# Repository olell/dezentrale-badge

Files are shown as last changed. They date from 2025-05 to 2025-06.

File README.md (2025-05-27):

# Dezentrale Blinky Logo

## Update Firmware

You can flash the latest Firmware directly using your web browser using [CH32WebFlash](https://olell.github.io/CH32WebFlashTool/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)

## Photos

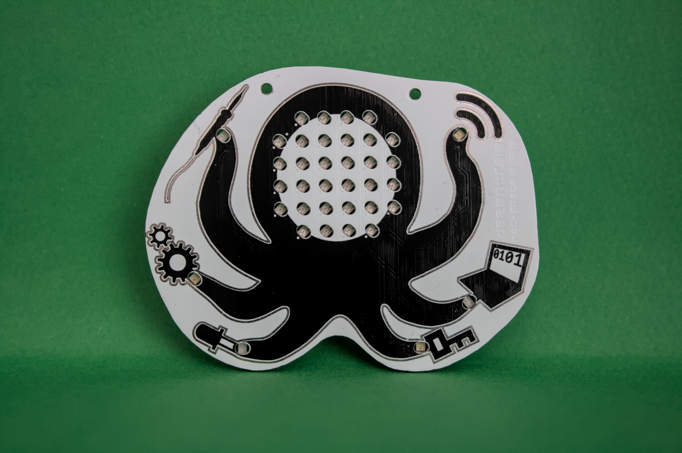
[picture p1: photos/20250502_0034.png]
front

back

## License

- Firmware source code is release under MIT License (C) 2025 Ole Lange
- The hardware is licensed under CC BY-NC-SA 4.0

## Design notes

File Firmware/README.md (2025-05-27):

# Dezentrale Badge Firmware

> **Note:** This project is a work in progress.

## Button actions:

| Press times | Action |
| --- | --- |
| 1x | Depends on animation |
| 2x | Depends on animation |
| 3x | Next animation |
| 4x | Go to sleep (wake by pressing the button) |
| 5x | Enter the USB bootloader |

## Setup

### 1. Toolchain

Find instructions to install the required dependencies and toolchain here: [ch32fun Installation Guide](https://github.com/cnlohr/ch32fun/wiki/Installation)

### 2. SDK

Run `git submodule update --init` to clone the ch32fun SDK

## Build & Flash

Navigate to the `Firmware` directory and run `make` to build and flash the firmware.

The provided `Makefile` includes a custom command for flashing the badge using an Ardulink programmer. If you need to change the serial port or use a different programmer, please update the Makefile accordingly. For the official WCH-LinkE, you can remove the custom flashing line.

### Flash using the USB bootloader

If your badge has the USB bootloader installed, you can flash it by connecting via USB. To enter the bootloader, follow these steps:

#### Option A: From firmware

You can enter the bootloader from firmware by pressing the button 5 times, the badge then starts to blink rapidly. To enter the
bootloader you now have to press the button again. By pressing the button 3x (animation change) you can abort entering the bootloader.

#### Option B: Pressing the button while power on

1. Remove the battery.
2. Insert the USB cable (if not already connected).
3. Press and hold the button.
4. Re-insert the battery while holding the button.

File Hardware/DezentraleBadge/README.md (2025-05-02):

# Dezentrale Badge Hardware Version 1

This folder contains the KiCad project for the BlinkyLogo V1

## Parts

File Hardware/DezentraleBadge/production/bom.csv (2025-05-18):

Designator | Footprint | Quantity | Value | LCSC Part #
BT101 | BatteryHolder_Multicomp_BC-2001_1x2032 | 1 | CR2032 | C6937139
C101 | 0805 | 1 | 100nF | C28233
D102, D103, D104, D105, D107, D108, D109, D110, D111, D112, D113, D114, D115, D116, D117, D118, D119, D120, D121, D122, D123, D124, D125, D126, D127, D128, D129, D130, D132, D133, D134, D135, D137, D138, D139, D140, D141, D142 | 1206 | 38 | LED_45deg | C3646940
J101 | Harwin_M20-89003xx_1x03_P2.54mm_Horizontal | 1 | PROG
J102 | USB_C_Receptacle_GCT_USB4110 | 1 | USB_C_Receptacle_USB2.0_16P
R101 | 0805 | 1 | 10kΩ | C17414
R102 | 0805 | 1 | 1.5kΩ | C17414
SW101 | SW_Push_1P1T_XKB_TS-1187A | 1 | Button | C318884
U101 | SOP-16_3.9x9.9mm_P1.27mm | 1 | CH32V003AxMx | C5346357

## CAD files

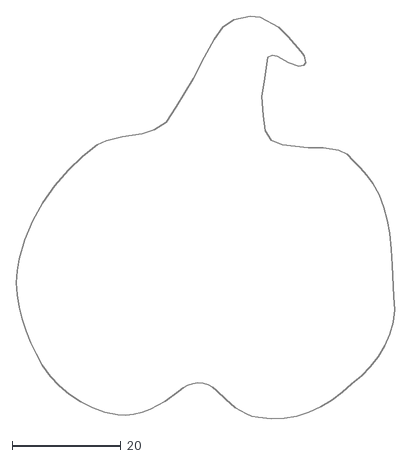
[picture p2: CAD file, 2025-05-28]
Hardware/Assets/outline_hacksen.dxf
69.7 x 74.2

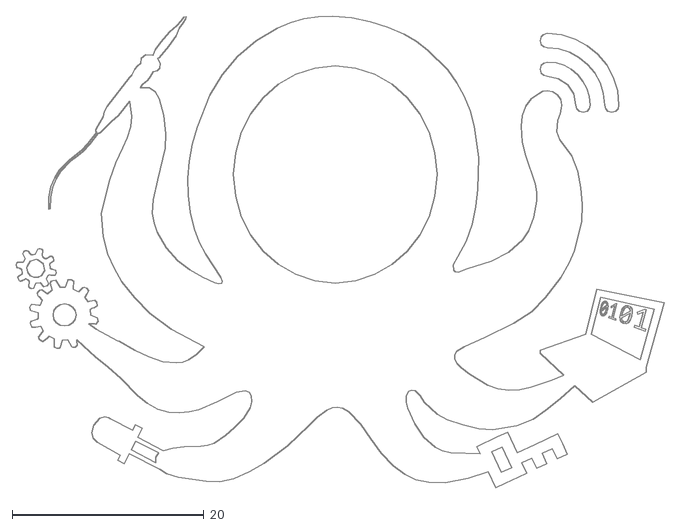
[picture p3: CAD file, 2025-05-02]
Hardware/Assets/dezentrale_logo_simple.dxf
67.6 x 49.1

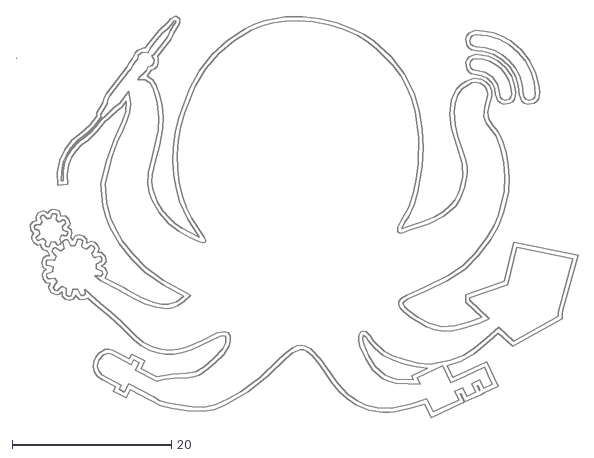
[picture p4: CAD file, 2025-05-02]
Hardware/Assets/extruded_outline.dxf
70.5 x 50.4

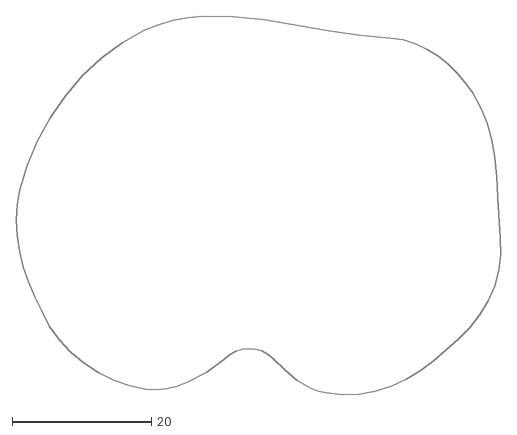
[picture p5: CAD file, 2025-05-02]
Hardware/Assets/outline.dxf
69.7 x 54.4

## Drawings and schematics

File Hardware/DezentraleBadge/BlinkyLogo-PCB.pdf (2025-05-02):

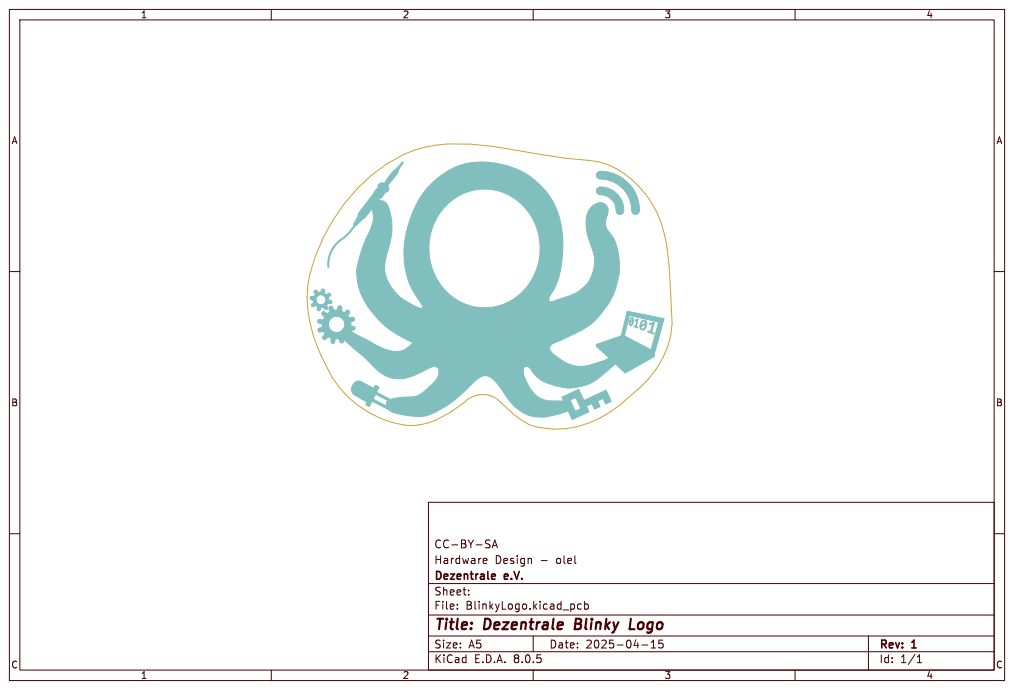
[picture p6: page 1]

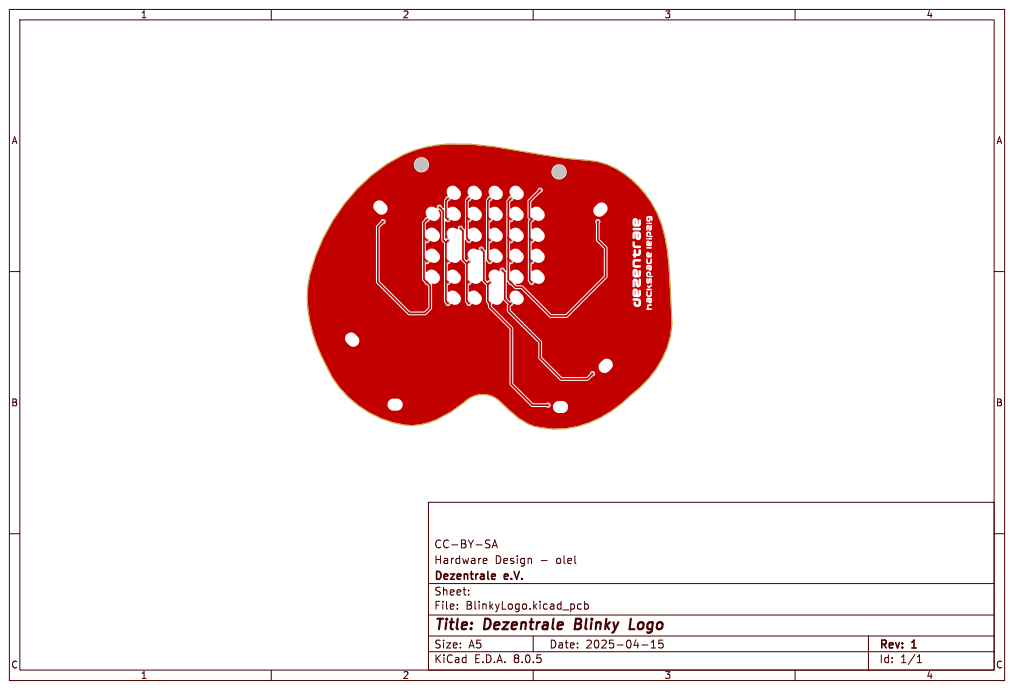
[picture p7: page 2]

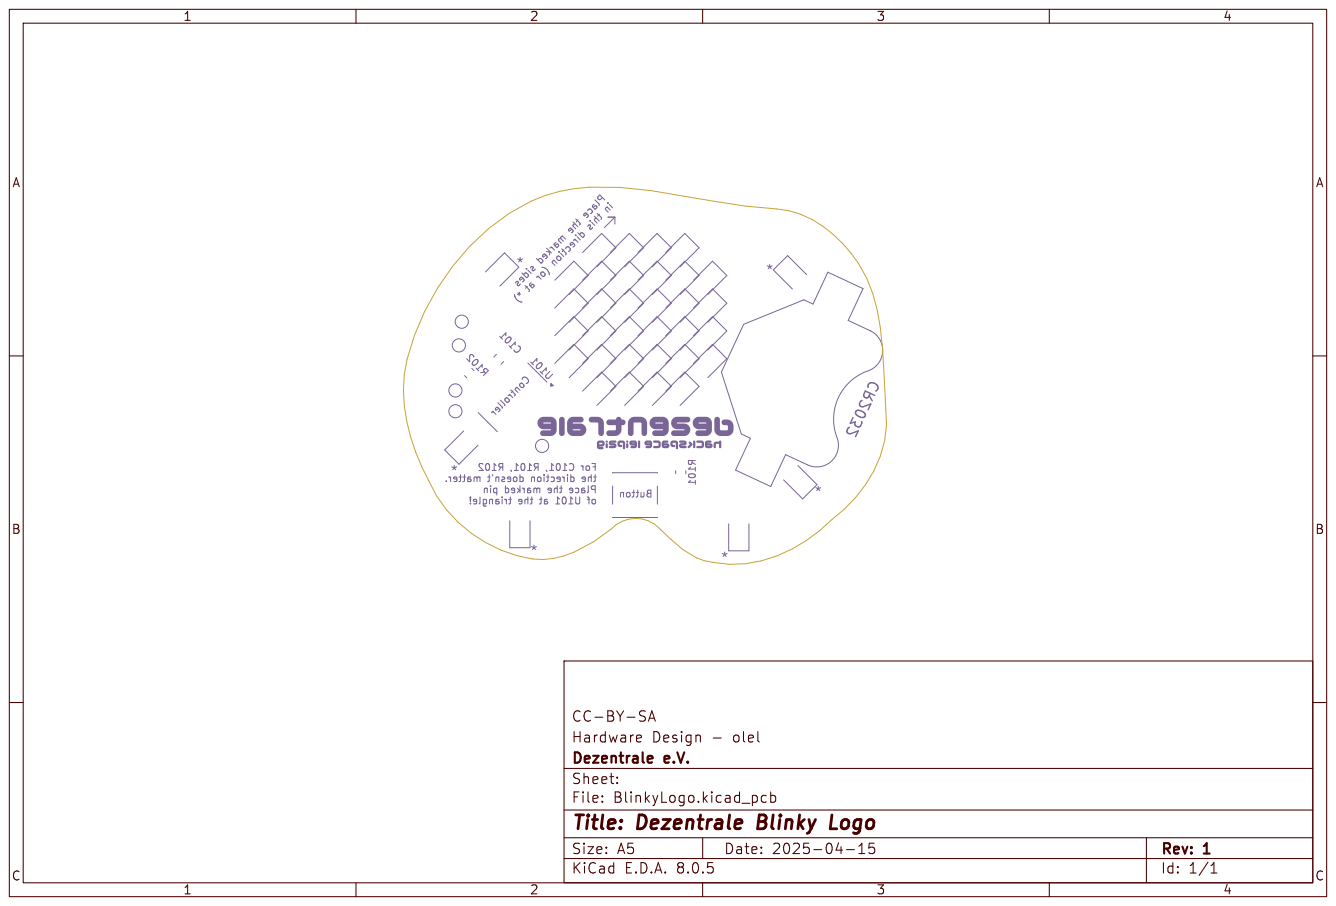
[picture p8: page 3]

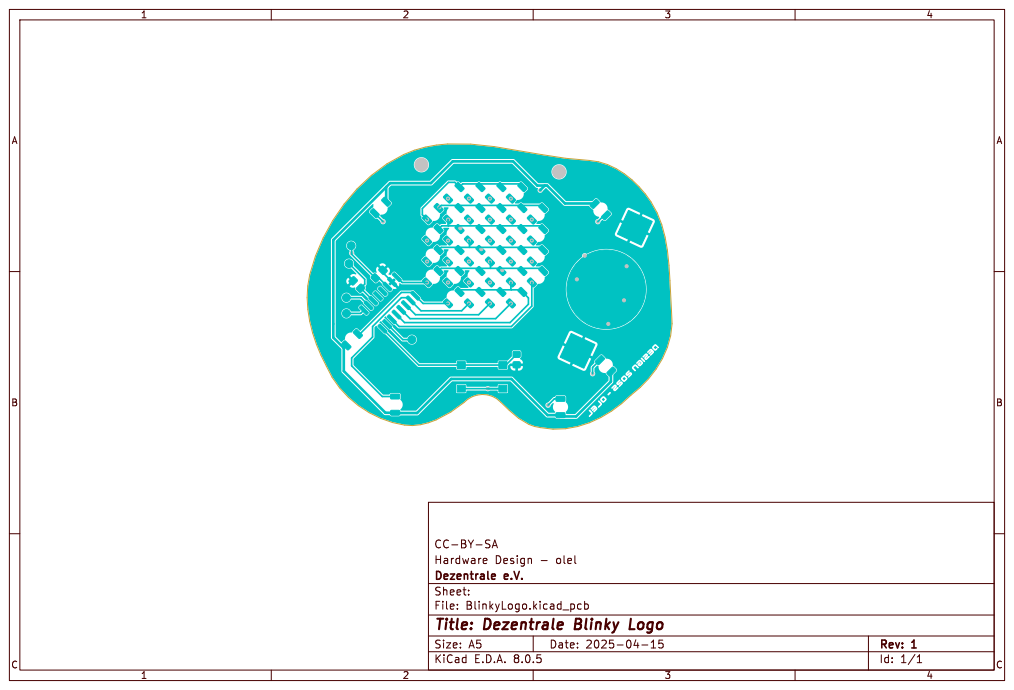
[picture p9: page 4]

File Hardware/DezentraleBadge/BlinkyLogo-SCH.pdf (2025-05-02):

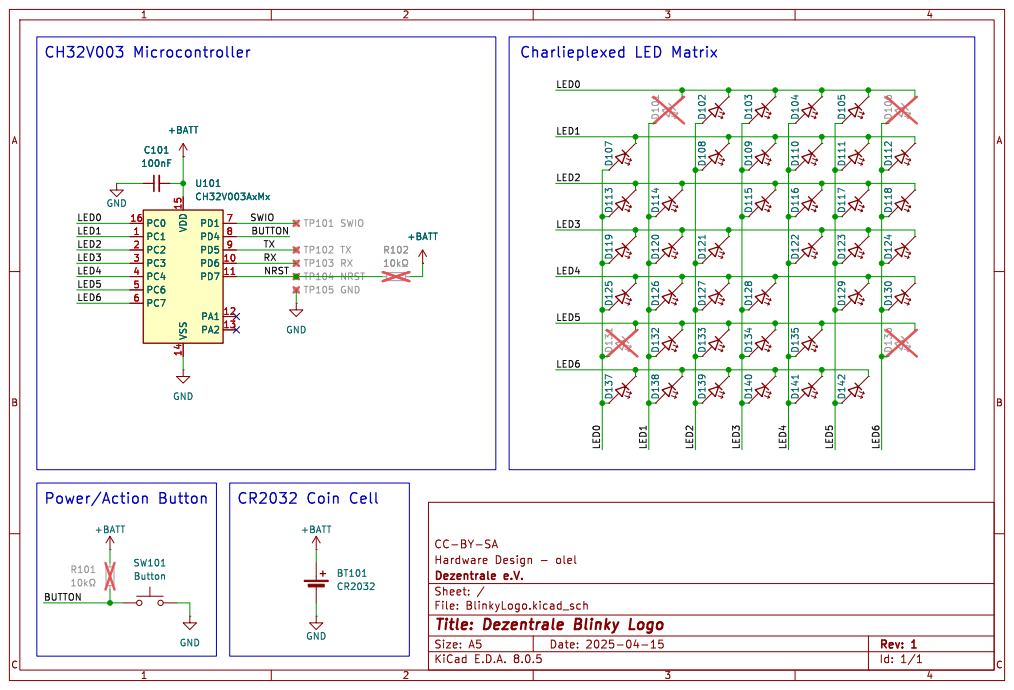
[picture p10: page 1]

Id: 1/1 Title: Dezentrale Blinky Logo

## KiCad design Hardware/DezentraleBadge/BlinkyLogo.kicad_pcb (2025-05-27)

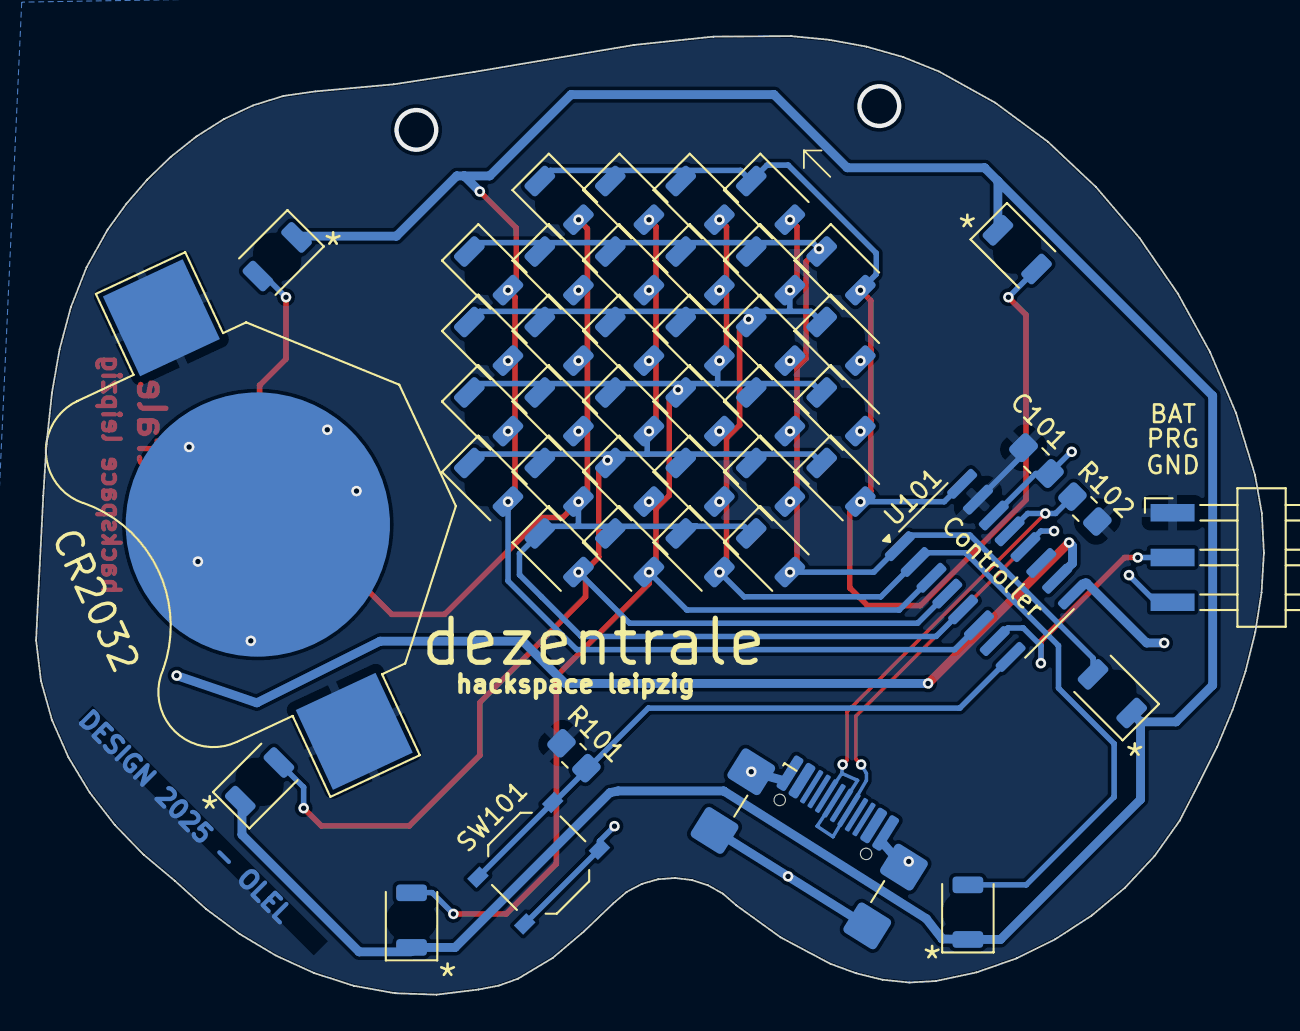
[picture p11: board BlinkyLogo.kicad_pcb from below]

Board: 2 copper layers, 69.7 x 54.4 mm, 46 parts (46 on the bottom side), 13 nets.

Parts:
BT101: CR2032; BatteryHolder_Multicomp_BC-2001_1x2032
C101: 100nF; C_0805_2012Metric_Pad1.18x1.45mm_HandSolder
D102, D103, D104, D105, D107, D108, D109, D110, D111, D112, D113, D114, D115, D116, D117, D118, D119, D120, D121, D122, D123, D124, D125, D126, D127, D128, D129, D130, D132, D133, D134, D135, D137, D138, D139, D140, D141, D142: LED_45deg; LED_1206_3216Metric_ReverseMount_Hole1.8x2.4mm
J101: PROG; Harwin_M20-89003xx_1x03_P2.54mm_Horizontal
J102: USB_C_Receptacle_USB2.0_16P; USB_C_Receptacle_GCT_USB4110
R101: 10kΩ; R_0805_2012Metric_Pad1.20x1.40mm_HandSolder
R102: 1.5kΩ; R_0805_2012Metric_Pad1.20x1.40mm_HandSolder
SW101: Button; SW_Push_1P1T_XKB_TS-1187A
U101: CH32V003AxMx; SOP-16_3.9x9.9mm_P1.27mm

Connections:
+BATT: BT101.1 (+), C101.2, J101.1, R101.2, R102.1, U101.15 (VDD)
/BUTTON: R101.1, SW101.1, U101.8 (PD4)
/LED0: D102.1 (K), D103.1 (K), D104.1 (K), D105.1 (K), D107.2 (A), D113.2 (A), D119.2 (A), D125.2 (A), D137.2 (A), U101.16 (PC0)
/LED1: D107.1 (K), D108.1 (K), D109.1 (K), D110.1 (K), D111.1 (K), D112.1 (K), D114.2 (A), D120.2 (A), D126.2 (A), D132.2 (A), D138.2 (A), U101.1 (PC1)
/LED2: D102.2 (A), D108.2 (A), D113.1 (K), D114.1 (K), D115.1 (K), D116.1 (K), D117.1 (K), D118.1 (K), D121.2 (A), D127.2 (A), D133.2 (A), D139.2 (A), U101.2 (PC2)
/LED3: D103.2 (A), D109.2 (A), D115.2 (A), D119.1 (K), D120.1 (K), D121.1 (K), D122.1 (K), D123.1 (K), D124.1 (K), D128.2 (A), D134.2 (A), D140.2 (A), U101.3 (PC3)
/LED4: D104.2 (A), D110.2 (A), D116.2 (A), D122.2 (A), D125.1 (K), D126.1 (K), D127.1 (K), D128.1 (K), D129.1 (K), D130.1 (K), D135.2 (A), D141.2 (A), U101.4 (PC4)
/LED5: D105.2 (A), D111.2 (A), D117.2 (A), D123.2 (A), D129.2 (A), D132.1 (K), D133.1 (K), D134.1 (K), D135.1 (K), D142.2 (A), U101.5 (PC6)
/LED6: D112.2 (A), D118.2 (A), D124.2 (A), D130.2 (A), D137.1 (K), D138.1 (K), D139.1 (K), D140.1 (K), D141.1 (K), D142.1 (K), U101.6 (PC7)
/SWIO: J101.2, U101.7 (PD1)
/USB_DN: J102.A7 (D-), J102.B7 (D-), R102.2, U101.13 (PA2)
/USB_DP: J102.A6 (D+), J102.B6 (D+), U101.12 (PA1)
GND: BT101.2 (-), C101.1, J101.3, J102.A1 (GND), J102.A12 (GND), J102.B1 (GND), J102.B12 (GND), J102.S1 (SHIELD), SW101.2, U101.14 (VSS)

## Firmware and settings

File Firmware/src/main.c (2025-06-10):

#include <stdio.h>

#include "ch32fun.h"
#include "matrix.h"
#include "systick.h"
#include "ch32v003_standby.h"
#include "animation.h"
#include "touch.h"

// include animations here, do not forget to register them below
#include "animations/cycle.h"
#include "animations/pulse.h"
#include "animations/rolling_text.h"
#include "animations/face.h"
#include "animations/fade.h"
#include "animations/bootloader.h"

 // max milliseconds between two pressed to be counted as multi-press
#define MULTI_PRESS_SPEED 500

size_t current_animation_idx;
const animation_t* current_animation;

// button interrupt handler
uint32_t btn_last_press = 0;
uint32_t btn_press = 0;
uint32_t btn_duration = 0;
uint32_t now = 0;
uint8_t btn_cnt = 0;

void EXTI7_0_IRQHandler( void ) __attribute__((interrupt));
void EXTI7_0_IRQHandler( void ) {
    now = millis();

    // debounce code
    if (now - btn_press < 50) {
        EXTI->INTFR = EXTI_Line4;
        return;
    };

    btn_last_press = btn_press;
    btn_press = now;

    if (btn_cnt == 0) btn_cnt = 1;

    // count how many time the button was pressed shortly
    if (btn_press - btn_last_press < MULTI_PRESS_SPEED) {
        btn_cnt += 1;
    }

    EXTI->INTFR = EXTI_Line4;
}

int main() {
    /* System init functions */
    SystemInit();
    
    funGpioInitC();
    funGpioInitD();

    systickInit();
    matrixInit();

    // setup deepsleep and wakeup using button
    standby_gpio_init();
    standby_gpio_assign_button(GPIOD, 4);
    standby_gpio_assign_pin(STANDBY_GPIO_PORT_D, 4, STANDBY_TRIGGER_DIRECTION_FALLING);

    // setup button interrupt
	AFIO->EXTICR = AFIO_EXTICR_EXTI4_PD;
	EXTI->INTENR = EXTI_INTENR_MR4;
	EXTI->RTENR = EXTI_RTENR_TR4;
    EXTI->FTENR &= ~EXTI_FTENR_TR4;

    NVIC_EnableIRQ( EXTI7_0_IRQn );

    touchInit();

    // register animations here, the animations are cycled through
    // by tripple pressing the button in this order
    register_animation(&rolling_text_animation);
    register_animation(&fade_animation);
    register_animation(&face_animation);
    register_animation(&pulse_animation);
    register_animation(&cycle_animation);

    if (get_animation_count() == 0) {
        printf("System cannot run without any animations!\n");
        while(1);
    }

    current_animation_idx = 0;
    current_animation = get_animation(current_animation_idx);
    current_animation->init();

    for (;;) {

        // repeat the loop until it breaks to sleep
        for (;;) {
            // Matrix animation
            current_animation->tick();

            Delay_Ms(current_animation->tick_interval);
            if (current_animation->flags & ANIM_USES_TOUCH) {
                touchUpdate();
            }
            
            // btn pressed at least once and more than MULTI_PRESS_SPEED ago
            // press count is captured by thea interrupt handler
            if (btn_cnt > 0 && millis() - btn_press > MULTI_PRESS_SPEED) {
                if (btn_cnt == 5) { // go to bootloader blink animation
                    current_animation = &bootloader_animation;
                    current_animation->init();
                }
                else if (btn_cnt == 4) { // go to sleep
                    btn_cnt = 0;
                    break;
                }
                else if (btn_cnt == 3) { // next animation
                    matrixClear();
                    current_animation_idx = (current_animation_idx + 1) % get_animation_count();
                    current_animation = get_animation(current_animation_idx);
                    current_animation->init();
                }
                else {
                    current_animation->on_press(btn_cnt);
                }
                btn_cnt = 0;
            }

        }

        /*
         * SLEEP CODE
         */

        // disable the systick & turn off the matrix
        systickClear();
        matrixPowerOff();
        NVIC_DisableIRQ(EXTI7_0_IRQn);

        // enter standby, it will hold until the button gets pressed
		standby_enter();

        // re-enables the systick for millis() and matrix updates
        systickInit();
        NVIC_EnableIRQ(EXTI7_0_IRQn);
        Delay_Ms(1000);
    }
}

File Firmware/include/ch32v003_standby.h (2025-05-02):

// Slightly modified ch32v003_standby.h from recallmenot/ch32v003fun_wildwest
// available at: https://github.com/recallmenot/ch32v003fun_wildwest/blob/main/lib/ch32v003_standby.h
// Licensed under the MIT License.

//######## necessities

// include guards
#ifndef CH32V003_STANDBY_H
#define CH32V003_STANDBY_H

// includes
#include<stdint.h>								//uintN_t support
#include"ch32fun.h"



/*######## library description

This library makes sending the CH32V003 to sleep easy.
You can use the auto-wakeup timer, a pin or both, to exit standby and resume operation.

Expect around 10uA total power consumption in standby.
The LSI oscillator used for auto-wakeup uses 0.6uA.

*/



/*######## library usage and configuration

## auto-wakeup timer

The auto-wakeup timer takes two arguments to set the delay:
a clock prescaler divider and a count which, when reached, triggers the auto-wakeup event.

The autowakeup delay can be calculated by:

t = AWUWR / (fLSI / AWUPSC)

Where AWUWR (the count) can be 1 to 63, fLSI is always 128000 and AWUPSC (the prescaler divider), for practical purposes is 2048, 4096, 10240 or 61440, though lower values are possible.
The maximum auto-wakeup delay is 30s.

## wake by GPIO pins

When using GPIO pins to wake, there is a limitation on which can be set to this task simultaneously.
A pin can only be connected to its preassigned event channel:
PA1, PC1 and PD1 can only be connected to event channel 1, so you will have to pick one of the three.
Likewise, one of PA2, PC2 and PD2 can be connected to event channel 2, etc.

*/



/*######## features: use your desired before #including this library!

to have standby_enter() automatically restore the HSI speed to 48MHz after standby (else it will be 24MHz)
#define STANDBY_RESTORE_HSI_48MHz
*/



//######## references: use these

// port definitions for the standby_gpio_assign functions
#define STANDBY_GPIO_PORT_A 0b00
#define STANDBY_GPIO_PORT_C 0b10
#define STANDBY_GPIO_PORT_D 0b11

// port definitions for the standby_gpio_assign_pin functions
#define STANDBY_TRIGGER_DIRECTION_RISING	0b01
#define STANDBY_TRIGGER_DIRECTION_FALLING	0b10
#define STANDBY_TRIGGER_DIRECTION_BOTH		0b11



//######## function overview (declarations): use these!

// initialize standby with auto-wakeup timer
static inline void standby_autowakeup_init(const uint8_t window_count, const uint8_t PWR_AWU_Prescaler);

// initialize standby with GPIO wakeup
static inline void standby_gpio_init();

// configure GPIO pin for wakeup
static inline void standby_gpio_assign_pin(uint8_t standby_gpio_port, uint8_t pin_number, uint8_t standby_trigger_direction);
// configure GPIO pin with pull-up for wakeup
static inline void standby_gpio_assign_button(GPIO_TypeDef* gpio_port, uint8_t pin_number);

// enter standby mode
static inline void standby_enter();



//######## internal function declarations



//######## internal variables



//######## preprocessor macros



//######## preprocessor #define requirements


//######## small function definitions, static inline



static inline void standby_autowakeup_init(const uint8_t window_count, const uint8_t PWR_AWU_Prescaler) {
	// enable power interface module clock
	RCC->APB1PCENR |= RCC_APB1Periph_PWR;

	// enable low speed oscillator (LSI)
	RCC->RSTSCKR |= RCC_LSION;
	while ((RCC->RSTSCKR & RCC_LSIRDY) == 0) {}

	// enable AutoWakeUp event
	EXTI->EVENR |= EXTI_Line9;
	EXTI->FTENR |= EXTI_Line9;

	// configure AWU prescaler
	PWR->AWUPSC |= PWR_AWU_Prescaler;

	// configure AWU window comparison value
	PWR->AWUWR &= ~0x3f;
	PWR->AWUWR |= window_count;

	// enable AWU
	PWR->AWUCSR |= (1 << 1);

	// select standby on power-down
	PWR->CTLR |= PWR_CTLR_PDDS;

	// peripheral interrupt controller send to deep sleep
	PFIC->SCTLR |= (1 << 2);
}



static inline void standby_gpio_init() {
	// enable alternate IO function module clock
	RCC->APB2PCENR |= RCC_AFIOEN;

	// select standby on power-down
	PWR->CTLR |= PWR_CTLR_PDDS;

	// peripheral interrupt controller send to deep sleep
	PFIC->SCTLR |= (1 << 2);
}



static inline void standby_gpio_assign_pin(uint8_t standby_gpio_port, uint8_t pin_number, uint8_t standby_trigger_direction) {
	// enable the correct GPIO port register
	RCC->APB2PCENR |= (1 << (2 + standby_gpio_port));

	// assign pin 2 interrupt from portD (0b11) to EXTI channel 2
	AFIO->EXTICR |= (uint32_t)(standby_gpio_port << (pin_number * 2));

	// enable line2 interrupt event
	EXTI->EVENR |= (1 << pin_number);

	// set trigger condition
	EXTI->RTENR |= (standby_trigger_direction & 0b01) * (1 << pin_number);
	EXTI->FTENR |= (standby_trigger_direction >> 1) * (1 << pin_number);
}



static inline void standby_gpio_assign_button(GPIO_TypeDef* gpio_port, uint8_t pin_number) {
	// configure button as input, pullup
	gpio_port->CFGLR &= ~(0xf << (pin_number * 4));
	gpio_port->CFGLR |= (GPIO_CNF_IN_PUPD) << (pin_number * 4);
	gpio_port->BSHR = (1 << pin_number);
}



static inline void standby_enter() {
	__WFE();
	// after standby, core clock will be 24MHz HSI
	#ifdef STANDBY_RESTORE_HSI_48MHz
	// restore clock to full speed
	SystemInit48HSI();
    #else
    SystemInit();
	#endif
}



//######## small internal function definitions, static inline



//######## implementation block
//#define CH32V003_LIBRARYNAME_IMPLEMENTATION //enable so LSP can give you text colors while working on the implementation block, disable for normal use of the library
#if defined(CH32V003_LIBRARYNAME_IMPLEMENTATION)



#endif // CH32V003_LIBRARYNAME_IMPLEMENTATION
#endif // CH32V003_LIBRARYNAME_H

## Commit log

2025-05-02 Added KiCad project
    [BlinkyLogo.kicad_pcb, BlinkyLogo.kicad_sch, bom.csv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]
2025-05-02 Added schematic/pcb pdf files
    [BlinkyLogo.kicad_pcb]
2025-05-04 Optimized matrix driver by precalculating register values
2025-05-04 impl button interrupt
2025-05-04 Fixed overflowing timer
2025-05-05 Disabling external interrupt while sleep
2025-05-18 Implemented capacitive touch buttons
2025-05-18 Bump HW rev 2
    [bom.csv, designators.csv, positions.csv]
2025-05-27 created assets
    [outline_hacksen.dxf]
2025-06-19 ⚡️ changed to fixed point arithmetic
    [touch.c]

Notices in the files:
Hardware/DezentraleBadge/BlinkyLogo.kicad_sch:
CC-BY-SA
